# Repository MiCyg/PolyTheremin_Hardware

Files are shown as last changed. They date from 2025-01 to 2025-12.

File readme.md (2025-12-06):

# Polytheremin Hardware


[← Back to main repository](https://github.com/MiCyg/PolyTheremin.git)

---

# PolyTheremin Test Platform  

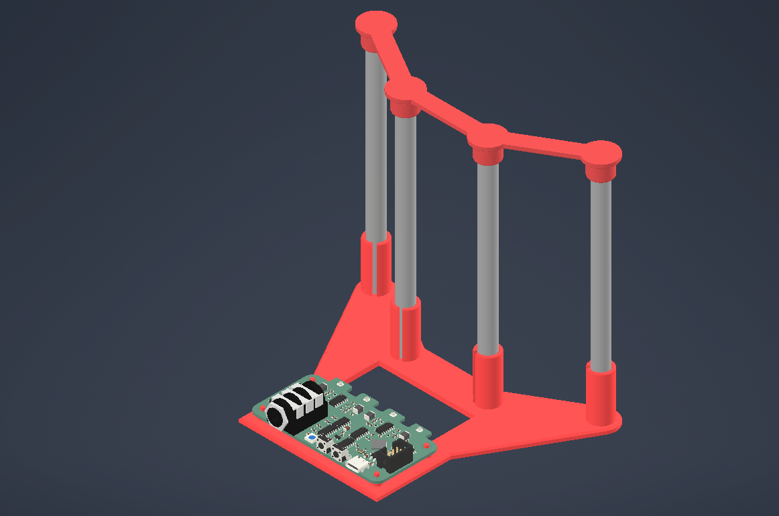
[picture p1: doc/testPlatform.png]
PolyTheremin Test Platform


# Description  

This test platform features a main board with four capacitive proximity sensors based on [OpenTheremin](https://github.com/GaudiLabs/OpenThereminV4) electronics.  

The key improvement in this version is the replacement of the fixed-frequency oscillator with a microcontroller-driven heterodyne frequency generator. This modification simplifies the circuit design and calibration process.  

The platform enables the analysis of antenna correlation errors, visualized on an XY plot.  
Its ultimate goal is to provide a functional example of a PolyTheremin with four independent oscillators, significantly reducing finger cross-correlation.

# PCB Characteristics  
- **Microcontroller**: RP2040  
- **LED**: One addressable LED for status indication  
- **Oscillator Modules**: Four theremin modules, independently connected to the microcontroller  
- **Audio Output**: Four 12-bit DACs (MCP4922) with a mixer and a 6.3mm jack socket  

# Block Schematic  
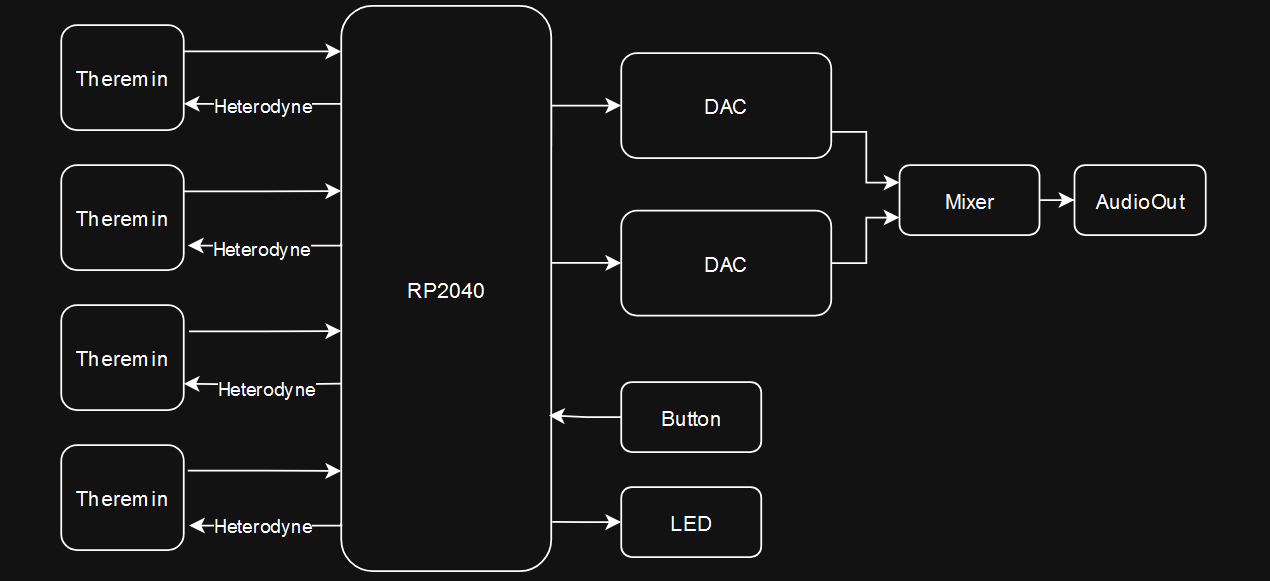
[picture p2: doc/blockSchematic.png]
Block Schematic


# 3D View  
3D View

# Contribution  

Contributions are welcome!  
If you have suggestions, encounter any issues, or want to discuss the project, feel free to contact me or open a pull request.

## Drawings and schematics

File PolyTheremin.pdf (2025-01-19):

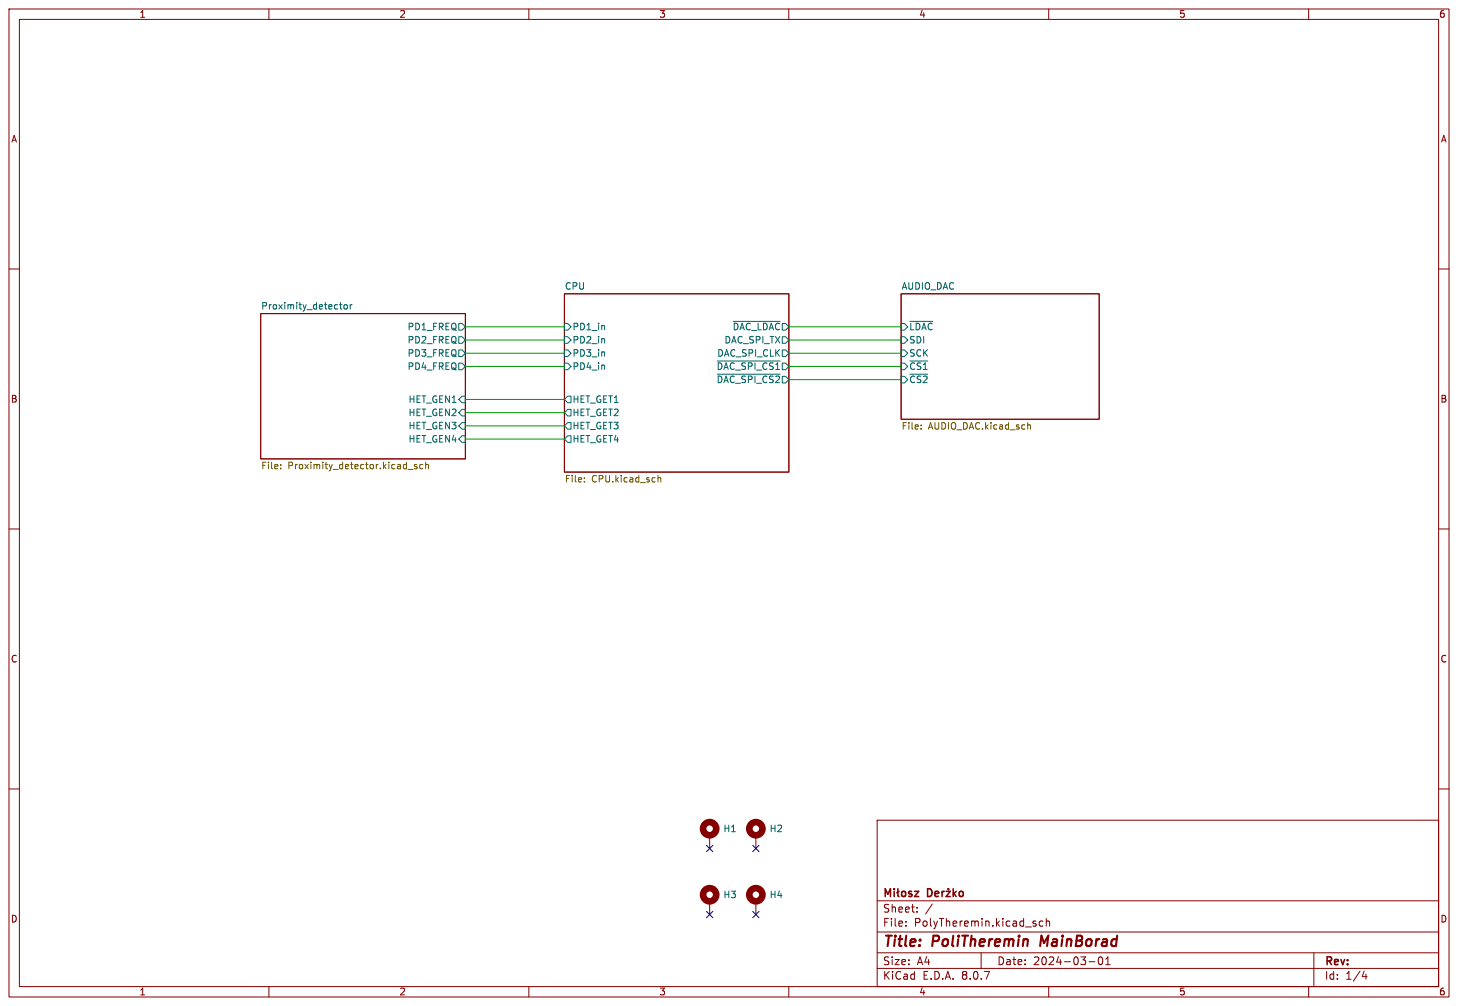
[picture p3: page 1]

File: PolyTheremin.kicad_sch Sheet: / þÿMiBosz þÿDer|ko

Id: 1/4 Title: PoliTheremin MainBorad

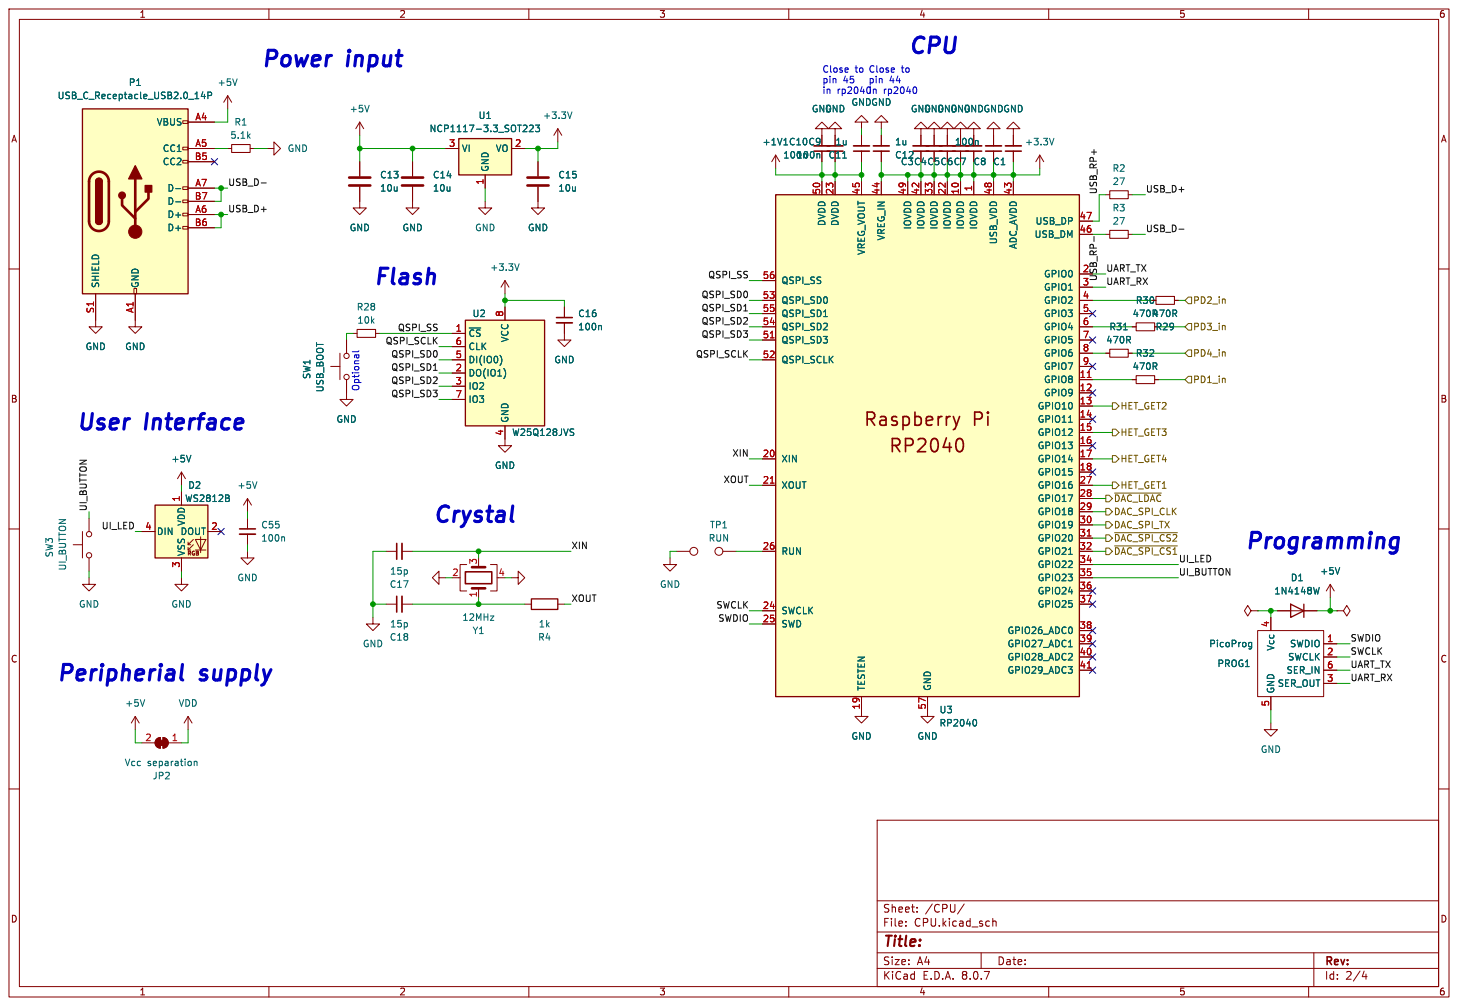
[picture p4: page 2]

1 IOVDD 10 GPIO8 11 GPIO9 12 GPIO10 13 GPIO11 14 GPIO12 15 GPIO13 16 GPIO14 17 GPIO15 18 TESTEN 19 GPIO0 2 XIN 20 XOUT 21 IOVDD 22 DVDD 23 SWCLK 24 SWD 25 RUN 26 GPIO16 27 GPIO17 28 GPIO18 29 GPIO1 3 GPIO19 30 GPIO20 31 GPIO21 32 IOVDD 33 GPIO22 34 GPIO23 35 GPIO24 36 GPIO25 37 GPIO26_ADC0 38 GPIO27_ADC1 39 GPIO2 4 GPIO28_ADC2 40 GPIO29_ADC3 41 IOVDD 42 ADC_AVDD 43 VREG_IN 44 VREG_VOUT 45 USB_DM 46 USB_DP 47 USB_VDD 48 IOVDD 49 GPIO3 5 DVDD 50 QSPI_SD3 51 QSPI_SCLK 52 QSPI_SD0 53 QSPI_SD2 54 QSPI_SD1 55 QSPI_SS 56 GND 57 GPIO4 6 GPIO5 7 GPIO6 8 GPIO7 9 U3 RP2040

1 IOVDD 10 GPIO8 11 GPIO9 12 GPIO10 13 GPIO11 14 GPIO12 15 GPIO13 16 GPIO14 17 GPIO15 18 TESTEN 19 GPIO0 2 XIN 20 XOUT 21 IOVDD 22 DVDD 23 SWCLK 24 SWD 25 RUN 26 GPIO16 27 GPIO17 28 GPIO18 29 GPIO1 3 GPIO19 30 GPIO20 31 GPIO21 32 IOVDD 33 GPIO22 34 GPIO23 35 GPIO24 36 GPIO25 37 GPIO26_ADC0 38 GPIO27_ADC1 39 GPIO2 4 GPIO28_ADC2 40 GPIO29_ADC3 41 IOVDD 42 ADC_AVDD 43 VREG_IN 44 VREG_VOUT 45 USB_DM 46 USB_DP 47 USB_VDD 48 IOVDD 49 GPIO3 5 DVDD 50 QSPI_SD3 51 QSPI_SCLK 52 QSPI_SD0 53 QSPI_SD2 54 QSPI_SD1 55 QSPI_SS 56 GND 57 GPIO4 6 GPIO5 7 GPIO6 8 GPIO7 9 GND

Id: 2/4 Title: File: CPU.kicad_sch Sheet: /CPU/ GND

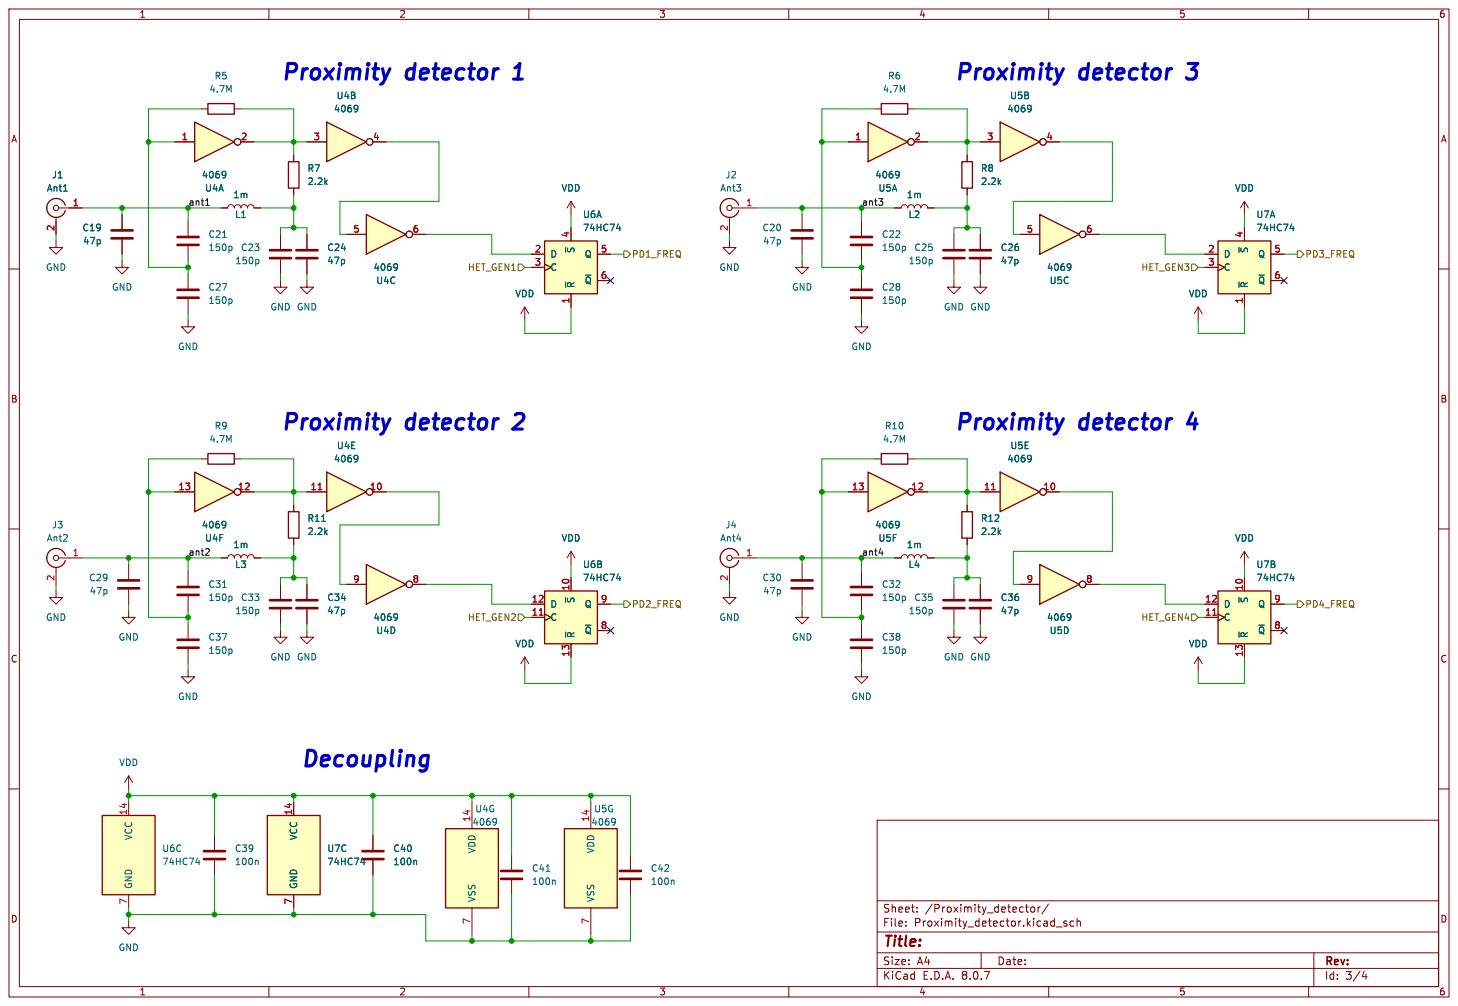
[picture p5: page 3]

Id: 3/4 Title: File: Proximity_detector.kicad_sch Sheet: /Proximity_detector/

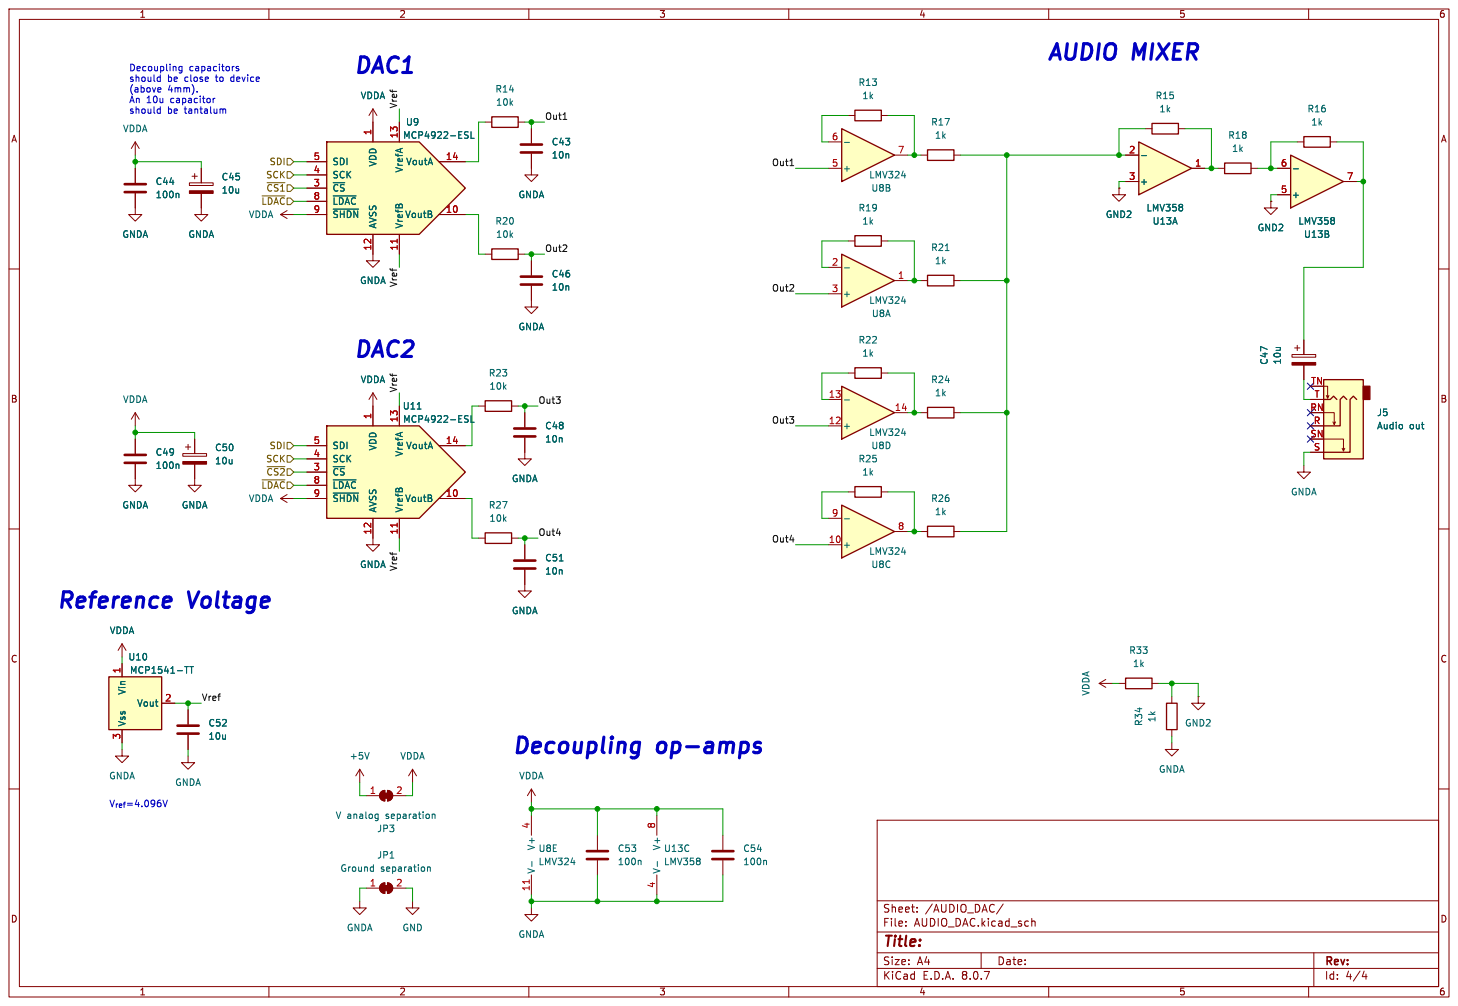
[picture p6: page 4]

should be close to device
100n VDDA

1 VoutB 10 VrefB 11 AVSS 12 VrefA 13 VoutA 14 ~{CS} 3 SCK 4 SDI 5 ~{LDAC} 8 ~{SHDN} 9 U9 MCP4922-ESL GNDA C44

1 VoutB 10 VrefB 11 AVSS 12 VrefA 13 VoutA 14 ~{CS} 3 SCK 4 SDI 5 ~{LDAC} 8 ~{SHDN} 9 GNDA C43

1 VoutB 10 VrefB 11 AVSS 12 VrefA 13 VoutA 14 ~{CS} 3 SCK 4 SDI 5 ~{LDAC} 8 ~{SHDN} 9 GNDA GNDA GNDA GNDAC52

1 VoutB 10 VrefB 11 AVSS 12 VrefA 13 VoutA 14 ~{CS} 3 SCK 4 SDI 5 ~{LDAC} 8 ~{SHDN} 9 U11 MCP4922-ESL R

1 Vout 2 Vss 3 U10 MCP1541-TT VDDA C50

Id: 4/4 Title: File: AUDIO_DAC.kicad_sch Sheet: /AUDIO_DAC/

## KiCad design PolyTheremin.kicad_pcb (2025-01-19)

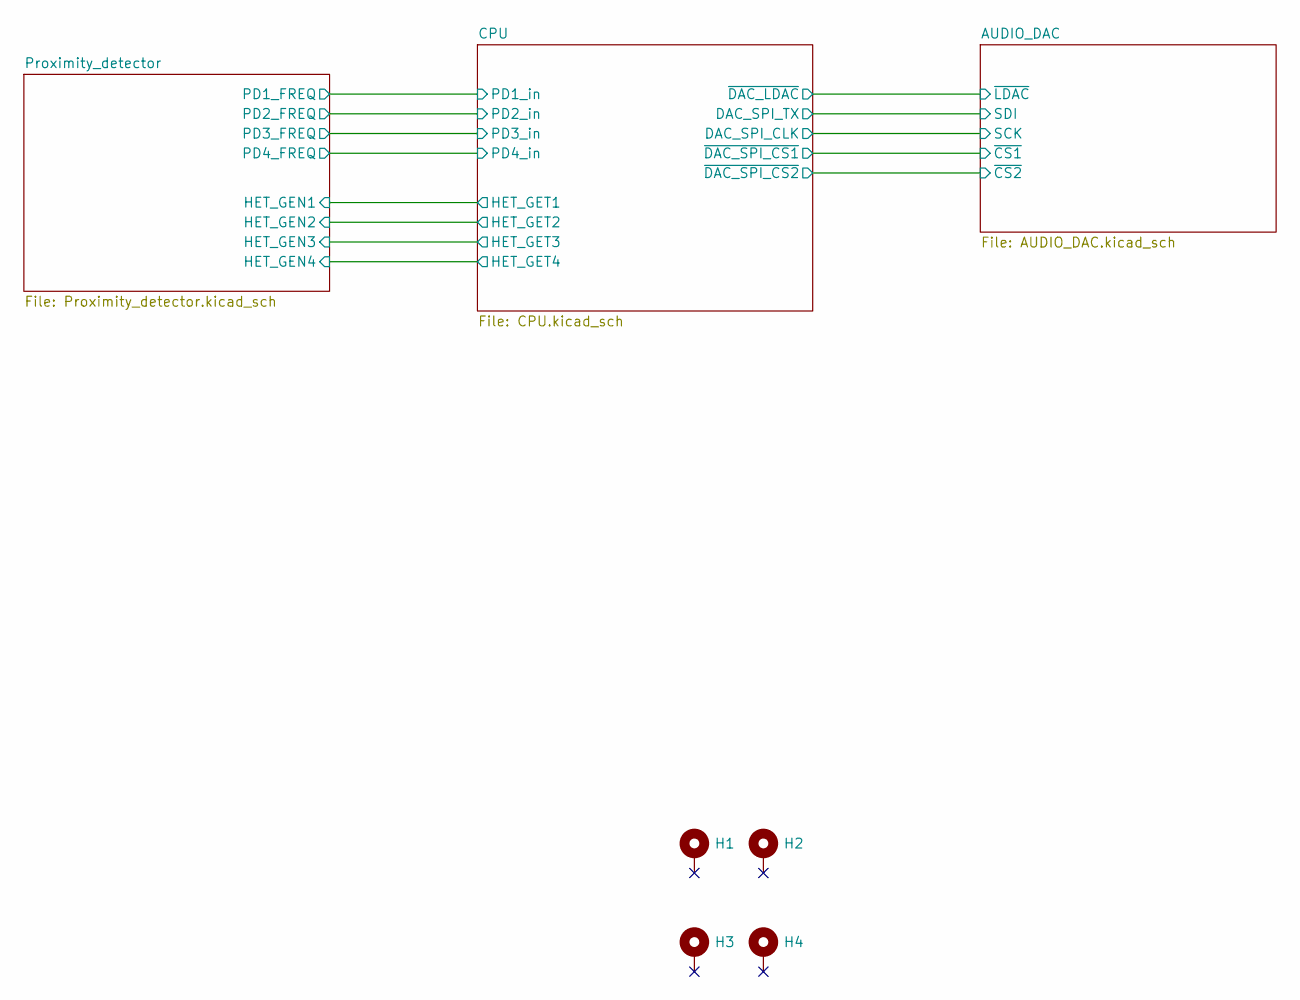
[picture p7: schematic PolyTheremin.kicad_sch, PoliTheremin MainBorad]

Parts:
H1, H2, H3, H4: MountingHole_Pad; MountingHole_3.2mm_M3_Pad_Via

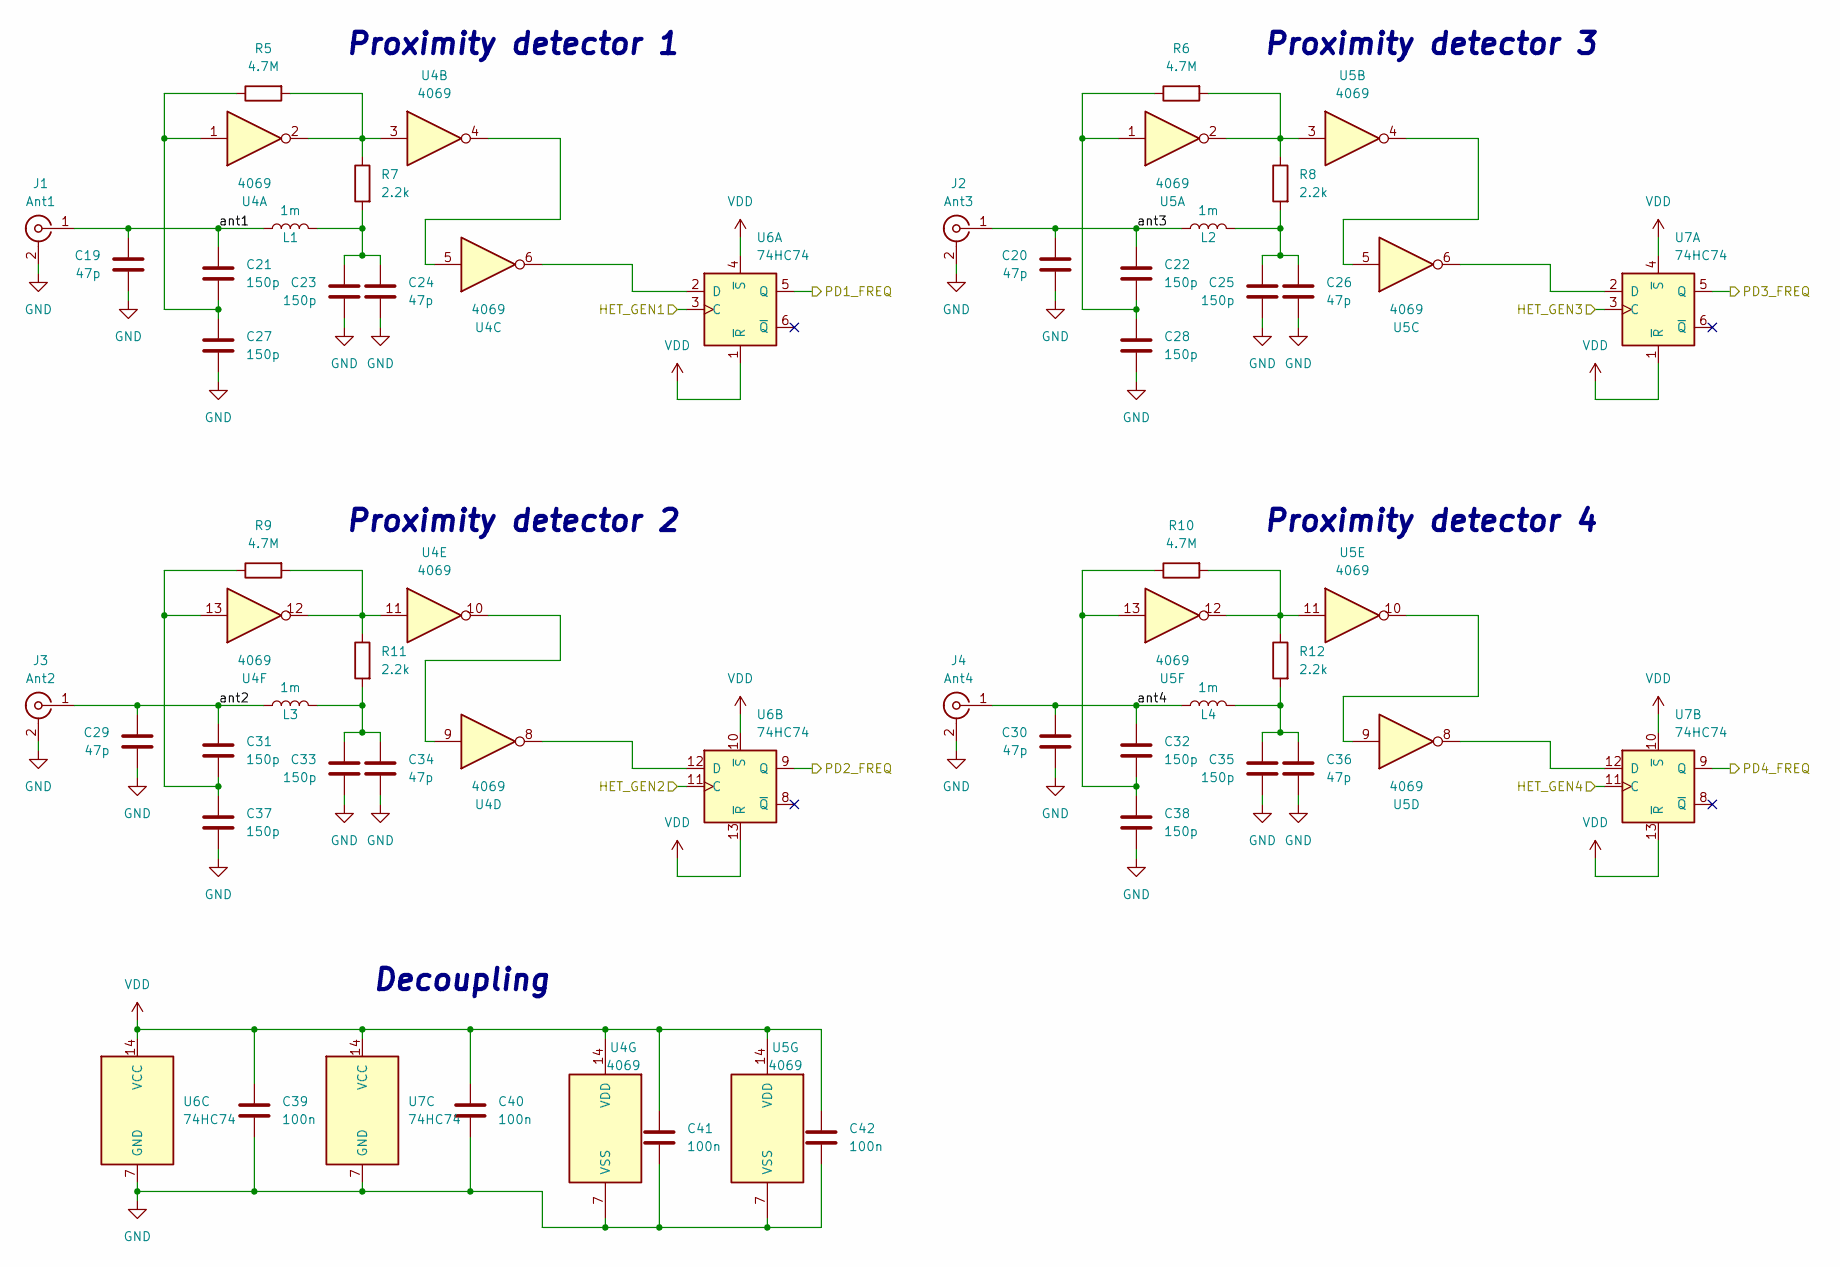
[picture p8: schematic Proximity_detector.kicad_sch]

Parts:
C19, C20, C24, C26, C29, C30, C34, C36: 47p; C_0603_1608Metric_Pad1.08x0.95mm_HandSolder
C21, C22, C23, C25, C27, C28, C31, C32, C33, C35, C37, C38: 150p; C_0603_1608Metric_Pad1.08x0.95mm_HandSolder
C39, C40, C41, C42: 100n; C_0603_1608Metric_Pad1.08x0.95mm_HandSolder
J1: Ant1; U.FL_Molex_MCRF_73412-0110_Vertical
J2: Ant3; U.FL_Molex_MCRF_73412-0110_Vertical
J3: Ant2; U.FL_Molex_MCRF_73412-0110_Vertical
J4: Ant4; U.FL_Molex_MCRF_73412-0110_Vertical
L1, L2, L3, L4: 1m; L_1812_4532Metric_Pad1.30x3.40mm_HandSolder
R5, R6, R9, R10: 4.7M; R_0603_1608Metric_Pad0.98x0.95mm_HandSolder
R7, R8, R11, R12: 2.2k; R_0603_1608Metric_Pad0.98x0.95mm_HandSolder
U4, U5: 4069; SOIC-14_3.9x8.7mm_P1.27mm
U6, U7: 74HC74; SOIC-14_3.9x8.7mm_P1.27mm

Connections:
/CPU/HET_GET1: U6.3 (C); also elsewhere on the board
/CPU/HET_GET2: U6.11 (C); also elsewhere on the board
/CPU/HET_GET3: U7.3 (C); also elsewhere on the board
/CPU/HET_GET4: U7.11 (C); also elsewhere on the board
/CPU/PD1_in: U6.5 (Q); also elsewhere on the board
/CPU/PD2_in: U6.9 (Q); also elsewhere on the board
/CPU/PD3_in: U7.5 (Q); also elsewhere on the board
/CPU/PD4_in: U7.9 (Q); also elsewhere on the board
/Proximity_detector/ant1: C19.1, C21.1, J1.1 (In), L1.2
/Proximity_detector/ant2: C29.1, C31.1, J3.1 (In), L3.2
/Proximity_detector/ant3: C20.1, C22.1, J2.1 (In), L2.2
/Proximity_detector/ant4: C30.1, C32.1, J4.1 (In), L4.2
GND: C19.2, C20.2, C23.2, C24.2, C25.2, C26.2, C27.2, C28.2, C29.2, C30.2, C33.2, C34.2, C35.2, C36.2, C37.2, C38.2, C39.2, C40.2, C41.2, C42.2, J1.2 (Ext), J2.2 (Ext), J3.2 (Ext), J4.2 (Ext), U4.7 (VSS), U5.7 (VSS), U6.7 (GND), U7.7 (GND); also elsewhere on the board
unnamed: C21.2, C27.1, R5.1, U4.1
unnamed: C22.2, C28.1, R6.1, U5.1
unnamed: C23.1, C24.1, L1.1, R7.2
unnamed: C25.1, C26.1, L2.1, R8.2
unnamed: C31.2, C37.1, R9.1, U4.13
unnamed: C32.2, C38.1, R10.1, U5.13
unnamed: C33.1, C34.1, L3.1, R11.2
unnamed: C35.1, C36.1, L4.1, R12.2
unnamed: R5.2, R7.1, U4.2, U4.3
unnamed: R6.2, R8.1, U5.2, U5.3
unnamed: R10.2, R12.1, U5.11, U5.12
unnamed: R9.2, R11.1, U4.11, U4.12
unnamed: U4.4, U4.5
unnamed: U4.9, U4.10
unnamed: U5.4, U5.5
unnamed: U5.9, U5.10
unnamed: U4.6, U6.2 (D)
unnamed: U4.8, U6.12 (D)
unnamed: U5.6, U7.2 (D)
unnamed: U5.8, U7.12 (D)
VDD: C39.1, C40.1, C41.1, C42.1, U4.14 (VDD), U5.14 (VDD), U6.1 (~R), U6.4 (~S), U6.10 (~S), U6.13 (~R), U6.14 (VCC), U7.1 (~R), U7.4 (~S), U7.10 (~S), U7.13 (~R), U7.14 (VCC); also elsewhere on the board

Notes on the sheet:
Decoupling
Proximity detector 1
Proximity detector 3
Proximity detector 4
Proximity detector 2

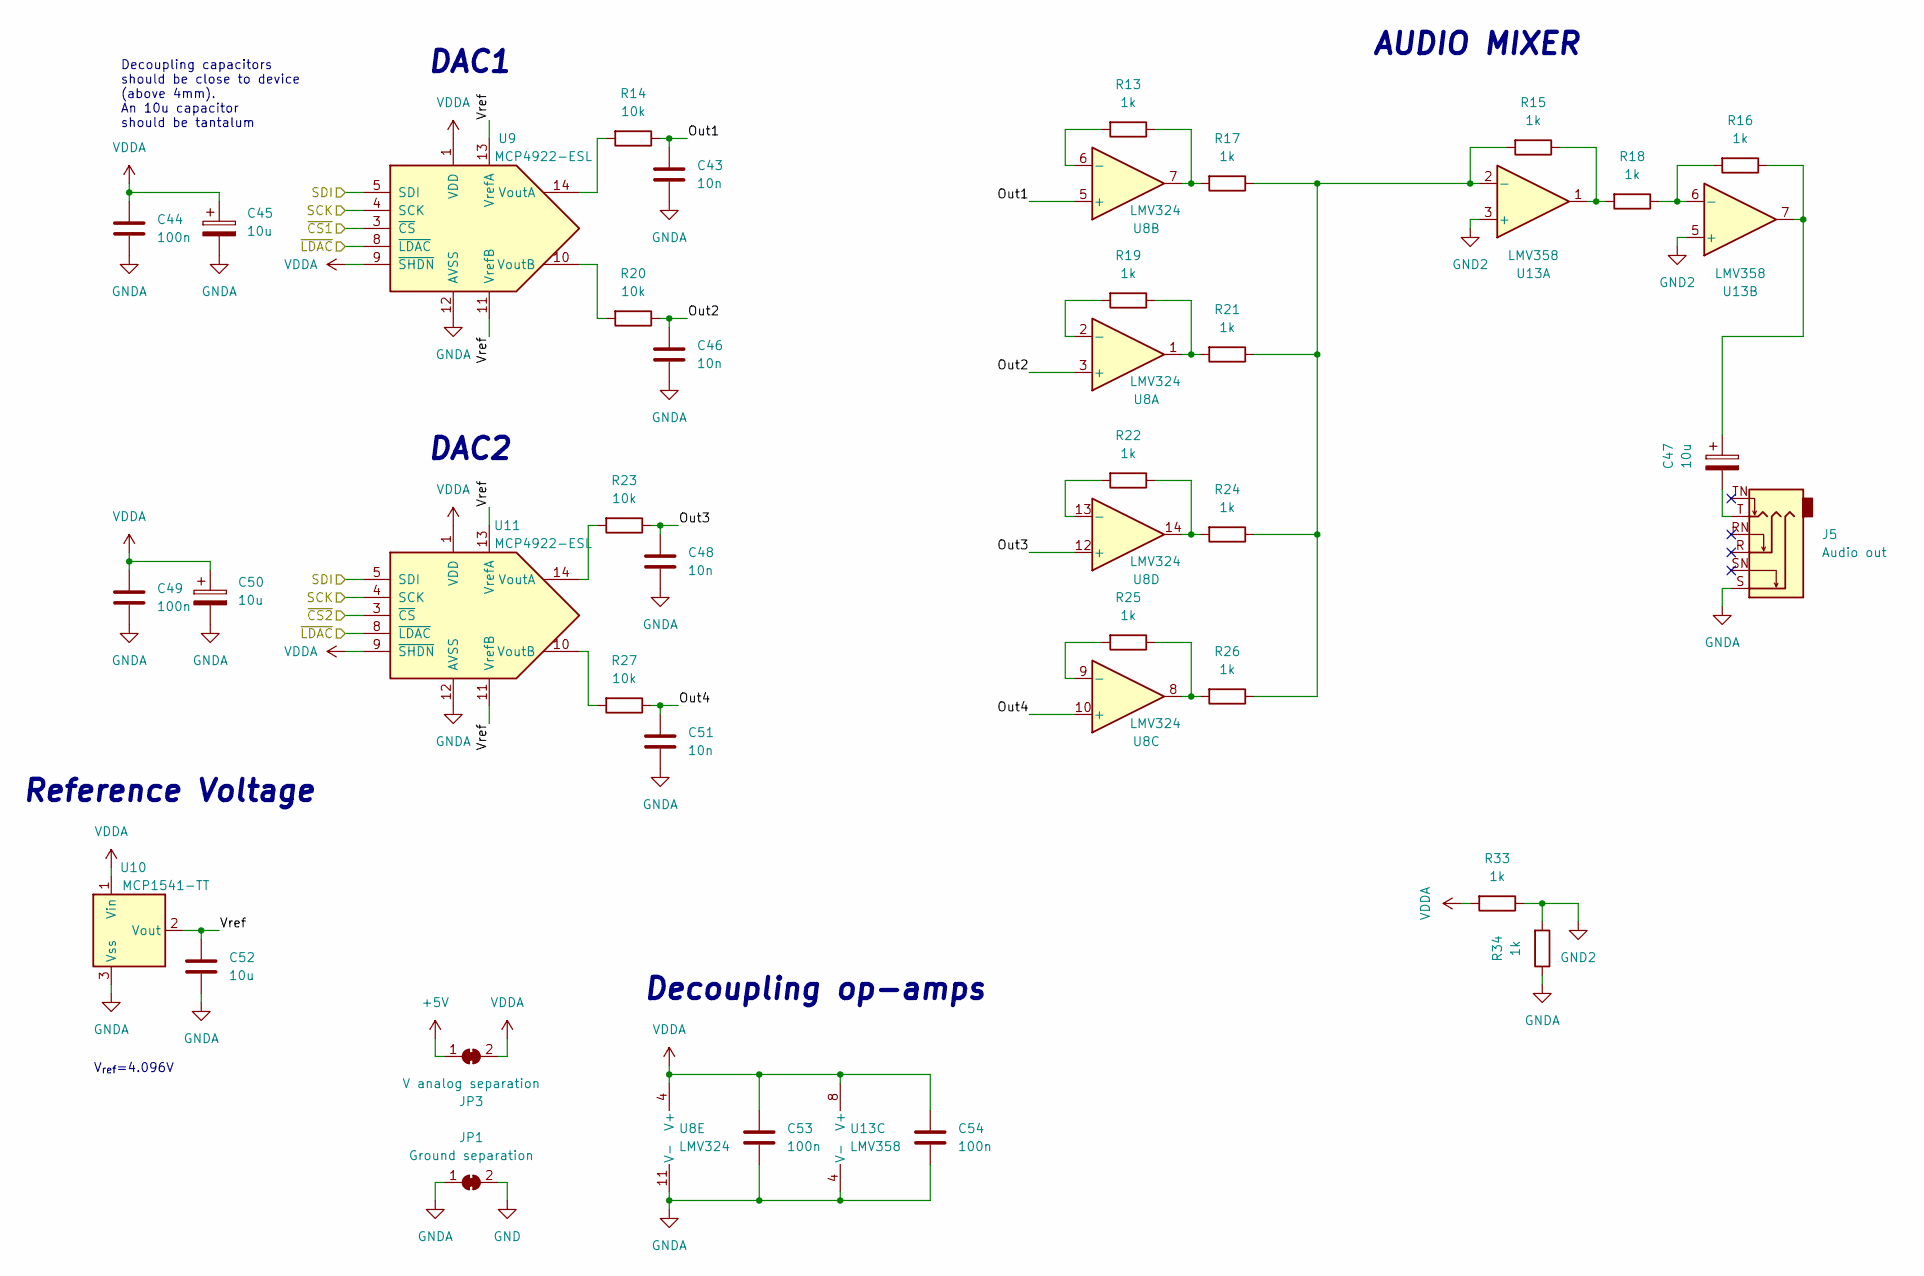
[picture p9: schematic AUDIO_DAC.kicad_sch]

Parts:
C43, C46, C48, C51: 10n; C_0603_1608Metric_Pad1.08x0.95mm_HandSolder
C44, C49, C53, C54: 100n; C_0603_1608Metric_Pad1.08x0.95mm_HandSolder
C45, C50: 10u; C_1206_3216Metric_Pad1.33x1.80mm_HandSolder
C47: 10u; C_0805_2012Metric_Pad1.18x1.45mm_HandSolder
C52: 10u; C_0603_1608Metric_Pad1.08x0.95mm_HandSolder
J5: Audio out; Jack_6.35mm_Neutrik_NMJ6HFD2_Horizontal
JP1: Ground separation; SolderJumper-2_P1.3mm_Open_RoundedPad1.0x1.5mm
JP3: V analog separation; SolderJumper-2_P1.3mm_Open_RoundedPad1.0x1.5mm
R13, R15, R16, R17, R18, R19, R21, R22, R24, R25, R26, R33, R34: 1k; R_0603_1608Metric_Pad0.98x0.95mm_HandSolder
R14, R20, R23, R27: 10k; R_0603_1608Metric_Pad0.98x0.95mm_HandSolder
U8: LMV324; SOIC-14_3.9x8.7mm_P1.27mm
U9, U11: MCP4922-ESL; SOIC-14_3.9x8.7mm_P1.27mm
U10: MCP1541-TT; SOT-23
U13: LMV358; SO-8_3.9x4.9mm_P1.27mm

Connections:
+5V: JP3.1 (A); also elsewhere on the board
/AUDIO_DAC/Out1: C43.1, R14.1, U8.5 (+)
/AUDIO_DAC/Out2: C46.1, R20.1, U8.3 (+)
/AUDIO_DAC/Out3: C48.1, R23.1, U8.12 (+)
/AUDIO_DAC/Out4: C51.1, R27.1, U8.10 (+)
/AUDIO_DAC/SCK: U9.4 (SCK), U11.4 (SCK); also elsewhere on the board
/AUDIO_DAC/SDI: U9.5 (SDI), U11.5 (SDI); also elsewhere on the board
/AUDIO_DAC/Vref: C52.1, U9.11 (VrefB), U9.13 (VrefA), U10.2 (Vout), U11.11 (VrefB), U11.13 (VrefA)
/AUDIO_DAC/~CS1: U9.3 (~CS); also elsewhere on the board
/AUDIO_DAC/~CS2: U11.3 (~CS); also elsewhere on the board
/AUDIO_DAC/~LDAC: U9.8 (~LDAC), U11.8 (~LDAC); also elsewhere on the board
GND: JP1.2 (B); also elsewhere on the board
unnamed: C47.1, R16.1, U13.7
unnamed: C47.2, J5.T
unnamed: R13.1, R17.2, U8.7
unnamed: R15.1, R18.2, U13.1
unnamed: R19.1, R21.2, U8.1
unnamed: R22.1, R24.2, U8.14
unnamed: R25.1, R26.2, U8.8
unnamed: R19.2, U8.2 (-)
unnamed: R13.2, U8.6 (-)
unnamed: R25.2, U8.9 (-)
unnamed: R22.2, U8.13 (-)
unnamed: R14.2, U9.14 (VoutA)
unnamed: R20.2, U9.10 (VoutB)
unnamed: R23.2, U11.14 (VoutA)
unnamed: R27.2, U11.10 (VoutB)
unnamed: R15.2, R17.1, R21.1, R24.1, R26.1, U13.2 (-)
unnamed: R16.2, R18.1, U13.6 (-)
VDDA: C44.1, C45.1, C49.1, C50.1, C53.1, C54.1, JP3.2 (B), R33.2, U8.4 (V+), U9.1 (VDD), U9.9 (~SHDN), U10.1 (Vin), U11.1 (VDD), U11.9 (~SHDN), U13.8 (V+)

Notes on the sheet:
AUDIO MIXER
Reference Voltage
DAC2
Decoupling op-amps
Decoupling capacitors should be close to device (above 4mm). An 10u capacitor should be tantalum
V_{ref}=4.096V
DAC1

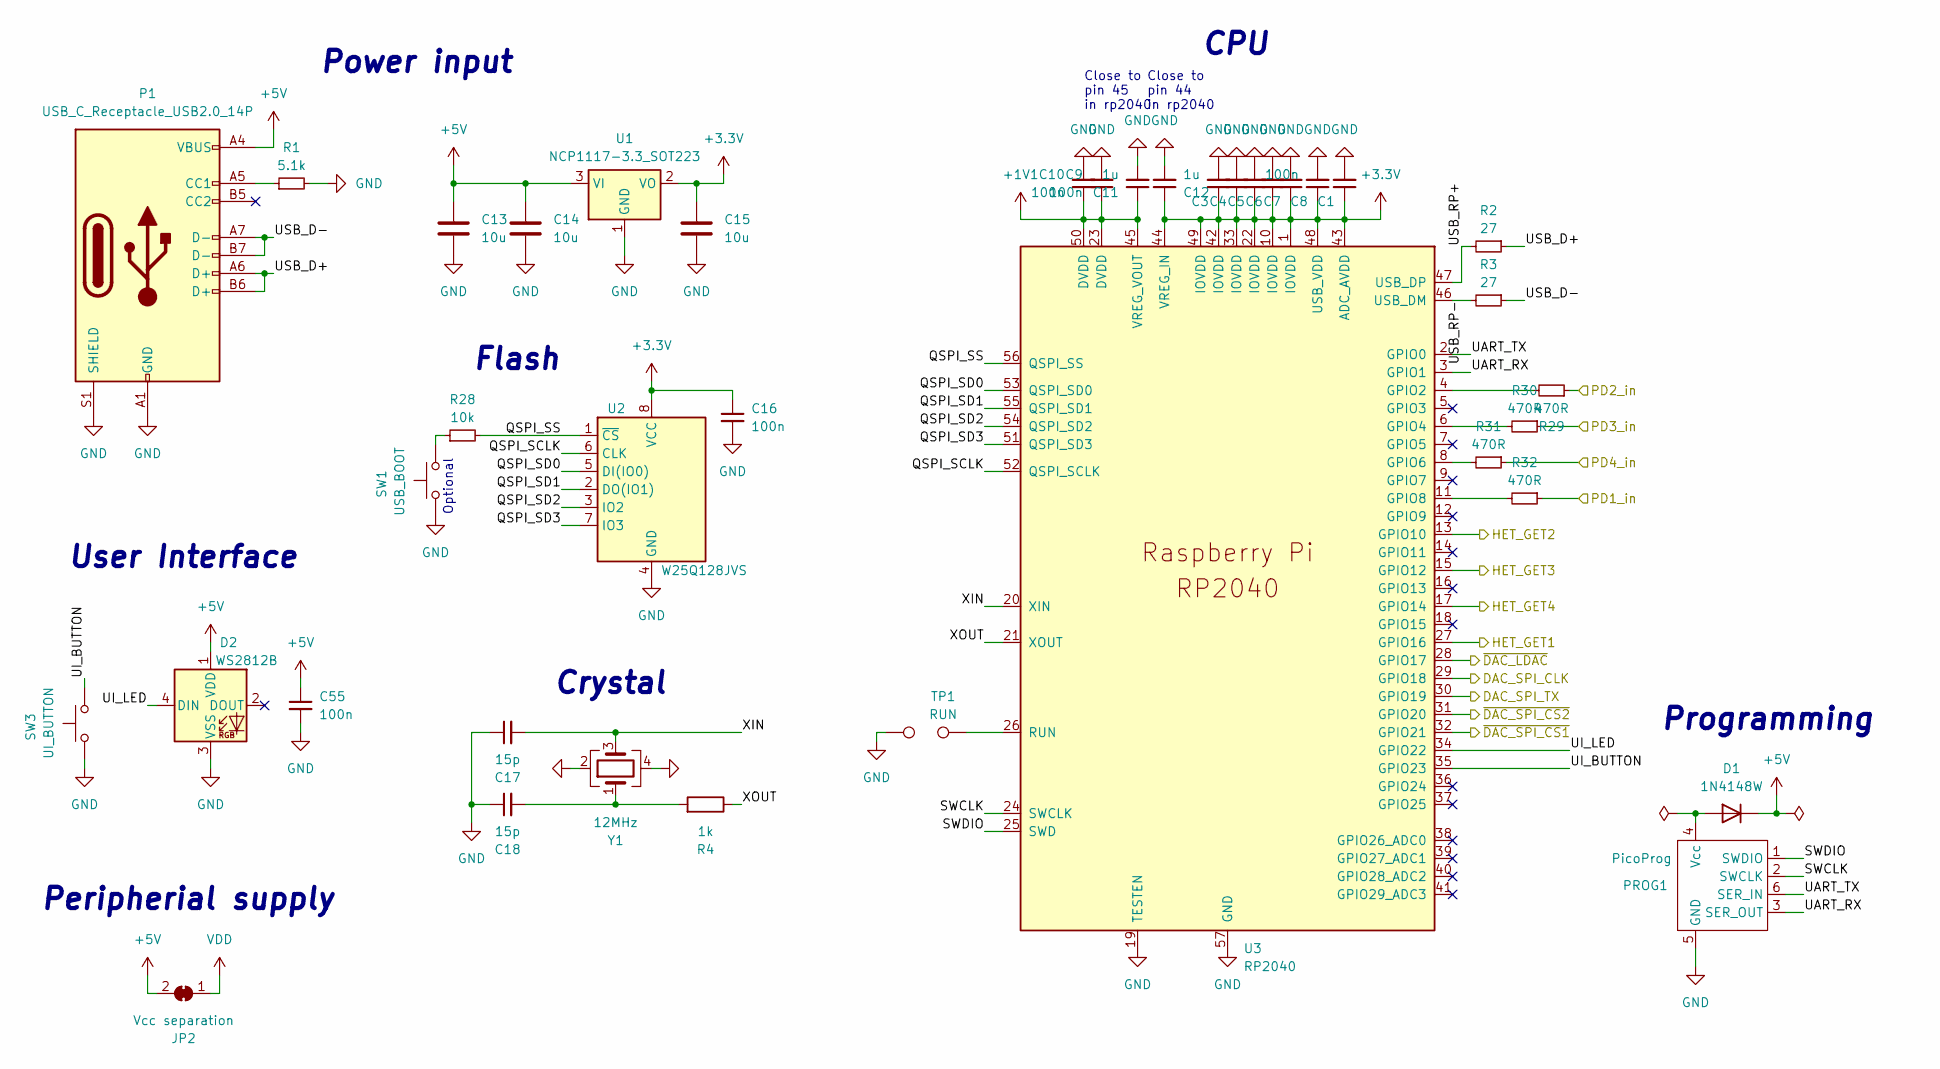
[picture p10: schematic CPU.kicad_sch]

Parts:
C1, C3, C4, C5, C6, C7, C8, C9, C10, C16, C55: 100n; C_0603_1608Metric_Pad1.08x0.95mm_HandSolder
C11, C12: 1u; C_0603_1608Metric_Pad1.08x0.95mm_HandSolder
C13, C14, C15: 10u; C_0805_2012Metric_Pad1.18x1.45mm_HandSolder
C17, C18: 15p; C_0603_1608Metric_Pad1.08x0.95mm_HandSolder
D1: 1N4148W; D_SOD-123
D2: WS2812B; LED_WS2812B_PLCC4_5.0x5.0mm_P3.2mm
JP2: Vcc separation; SolderJumper-2_P1.3mm_Open_RoundedPad1.0x1.5mm
P1: USB_C_Receptacle_USB2.0_14P; USB_C_Receptacle_G-Switch_GT-USB-7010ASV
PROG1: PicoProg; IDC-Header_2x03_P2.54mm_Vertical
R1: 5.1k; R_0603_1608Metric_Pad0.98x0.95mm_HandSolder
R2, R3: 27; R_0603_1608Metric_Pad0.98x0.95mm_HandSolder
R4: 1k; R_0603_1608Metric_Pad0.98x0.95mm_HandSolder
R28: 10k; R_0603_1608Metric_Pad0.98x0.95mm_HandSolder
R29, R30, R31, R32: 470R; R_0603_1608Metric_Pad0.98x0.95mm_HandSolder
SW1: USB_BOOT; SW_Tactile_SPST_Angled_PTS645Vx31-2LFS
SW3: UI_BUTTON; SW_Tactile_SPST_Angled_PTS645Vx31-2LFS
TP1: RUN
TP2: TestPoint
U1: NCP1117-3.3_SOT223; SOT-223-3_TabPin2
U2: W25Q128JVS; SOIC-8_5.23x5.23mm_P1.27mm
U3: RP2040; QFN-56-1EP_7x7mm_P0.4mm_EP3.2x3.2mm
Y1: 12MHz; Crystal_SMD_2520-4Pin_2.5x2.0mm

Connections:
+1V1: C9.1, C10.1, C11.1, U3.23 (DVDD), U3.45 (VREG_VOUT), U3.50 (DVDD)
+3.3V: C1.1, C3.1, C4.1, C5.1, C6.1, C7.1, C8.1, C12.1, C15.1, C16.1, U1.2 (VO), U2.8 (VCC), U3.1 (IOVDD), U3.10 (IOVDD), U3.22 (IOVDD), U3.33 (IOVDD), U3.42 (IOVDD), U3.43 (ADC_AVDD), U3.44 (VREG_IN), U3.48 (USB_VDD), U3.49 (IOVDD)
+5V: C13.1, C14.1, C55.1, D1.1 (K), D2.1 (VDD), JP2.2 (B), P1.A4 (VBUS), P1.A9 (VBUS), P1.B4 (VBUS), P1.B9 (VBUS), U1.3 (VI); also elsewhere on the board
/AUDIO_DAC/SCK: U3.29 (GPIO18); also elsewhere on the board
/AUDIO_DAC/SDI: U3.30 (GPIO19); also elsewhere on the board
/AUDIO_DAC/~CS1: U3.32 (GPIO21); also elsewhere on the board
/AUDIO_DAC/~CS2: U3.31 (GPIO20); also elsewhere on the board
/AUDIO_DAC/~LDAC: U3.28 (GPIO17); also elsewhere on the board
/CPU/HET_GET1: U3.27 (GPIO16); also elsewhere on the board
/CPU/HET_GET2: U3.13 (GPIO10); also elsewhere on the board
/CPU/HET_GET3: U3.15 (GPIO12); also elsewhere on the board
/CPU/HET_GET4: U3.17 (GPIO14); also elsewhere on the board
/CPU/PD1_in: R32.1; also elsewhere on the board
/CPU/PD2_in: R29.1; also elsewhere on the board
/CPU/PD3_in: R30.1; also elsewhere on the board
/CPU/PD4_in: R31.1; also elsewhere on the board
/CPU/QSPI_SCLK: U2.6 (CLK), U3.52 (QSPI_SCLK)
/CPU/QSPI_SD0: U2.5 (DI(IO0)), U3.53 (QSPI_SD0)
/CPU/QSPI_SD1: U2.2 (DO(IO1)), U3.55 (QSPI_SD1)
/CPU/QSPI_SD2: U2.3 (IO2), U3.54 (QSPI_SD2)
/CPU/QSPI_SD3: U2.7 (IO3), U3.51 (QSPI_SD3)
/CPU/QSPI_SS: R28.2, U2.1 (~CS), U3.56 (QSPI_SS)
/CPU/SWCLK: PROG1.2 (SWCLK), U3.24 (SWCLK)
/CPU/SWDIO: PROG1.1 (SWDIO), U3.25 (SWD)
/CPU/UART_RX: PROG1.3 (SER_OUT), U3.3 (GPIO1)
/CPU/UART_TX: PROG1.6 (SER_IN), U3.2 (GPIO0)
/CPU/UI_BUTTON: SW3.1, U3.35 (GPIO23)
/CPU/UI_LED: D2.4 (DIN), U3.34 (GPIO22)
/CPU/USB_D+: P1.A6 (D+), P1.B6 (D+), R2.1
/CPU/USB_D-: P1.A7 (D-), P1.B7 (D-), R3.1
/CPU/USB_RP+: R2.2, U3.47 (USB_DP)
/CPU/USB_RP-: R3.2, U3.46 (USB_DM)
/CPU/XIN: C17.2, U3.20 (XIN), Y1.3
/CPU/XOUT: R4.1, U3.21 (XOUT)
GND: C1.2, C3.2, C4.2, C5.2, C6.2, C7.2, C8.2, C9.2, C10.2, C11.2, C12.2, C13.2, C14.2, C15.2, C16.2, C17.1, C18.1, C55.2, D2.3 (VSS), P1.A1 (GND), P1.A12 (GND), P1.B1 (GND), P1.B12 (GND), P1.S1 (SHIELD), PROG1.5 (GND), R1.2, SW1.2, SW3.2, TP2.1, U1.1 (GND), U2.4 (GND), U3.19 (TESTEN), U3.57 (GND), Y1.2, Y1.4; also elsewhere on the board
unnamed: C18.2, R4.2, Y1.1
unnamed: D1.2 (A), PROG1.4 (Vcc)
unnamed: P1.A5 (CC1), R1.1
unnamed: R28.1, SW1.1
unnamed: TP1.1, U3.26 (RUN)
unnamed: R29.2, U3.4 (GPIO2)
unnamed: R30.2, U3.6 (GPIO4)
unnamed: R31.2, U3.8 (GPIO6)
unnamed: R32.2, U3.11 (GPIO8)
VDD: JP2.1 (A); also elsewhere on the board

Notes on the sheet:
Flash
Close to pin 44 in rp2040
Crystal
Close to pin 45 in rp2040
Peripherial supply
Optional
CPU
User Interface
Programming
Power input

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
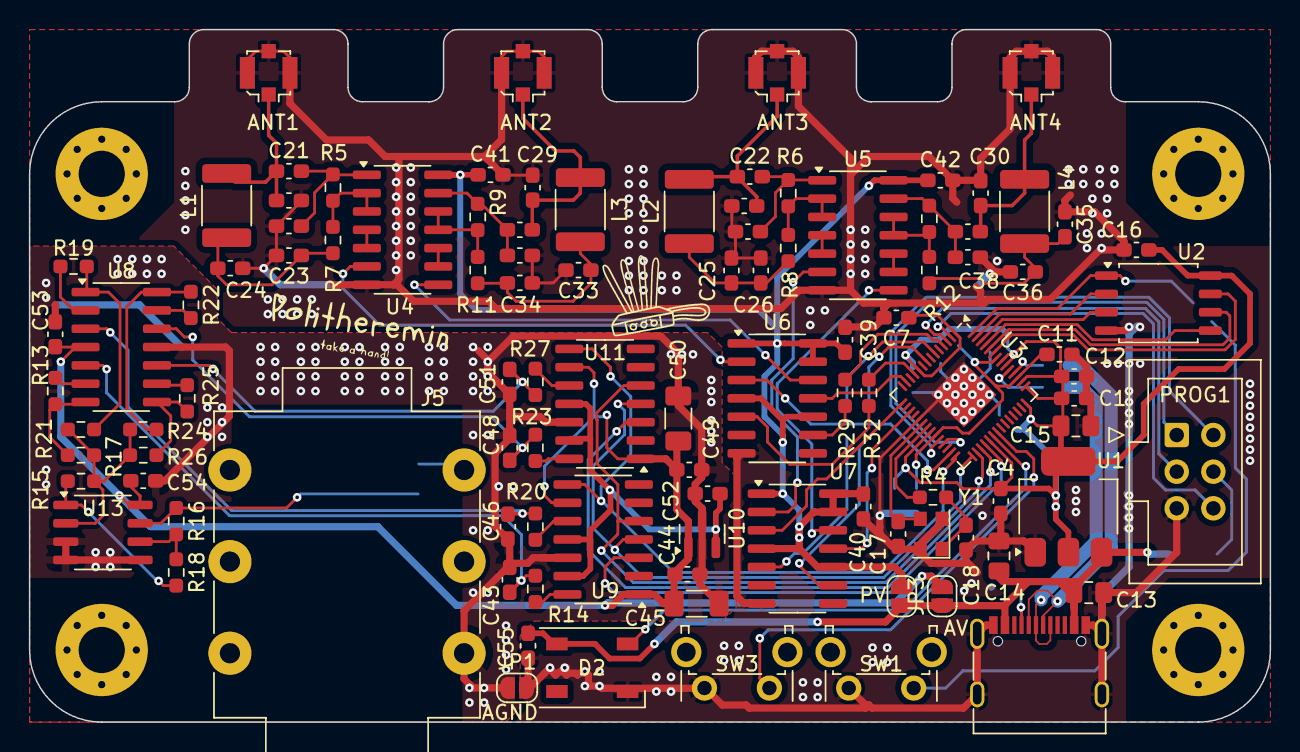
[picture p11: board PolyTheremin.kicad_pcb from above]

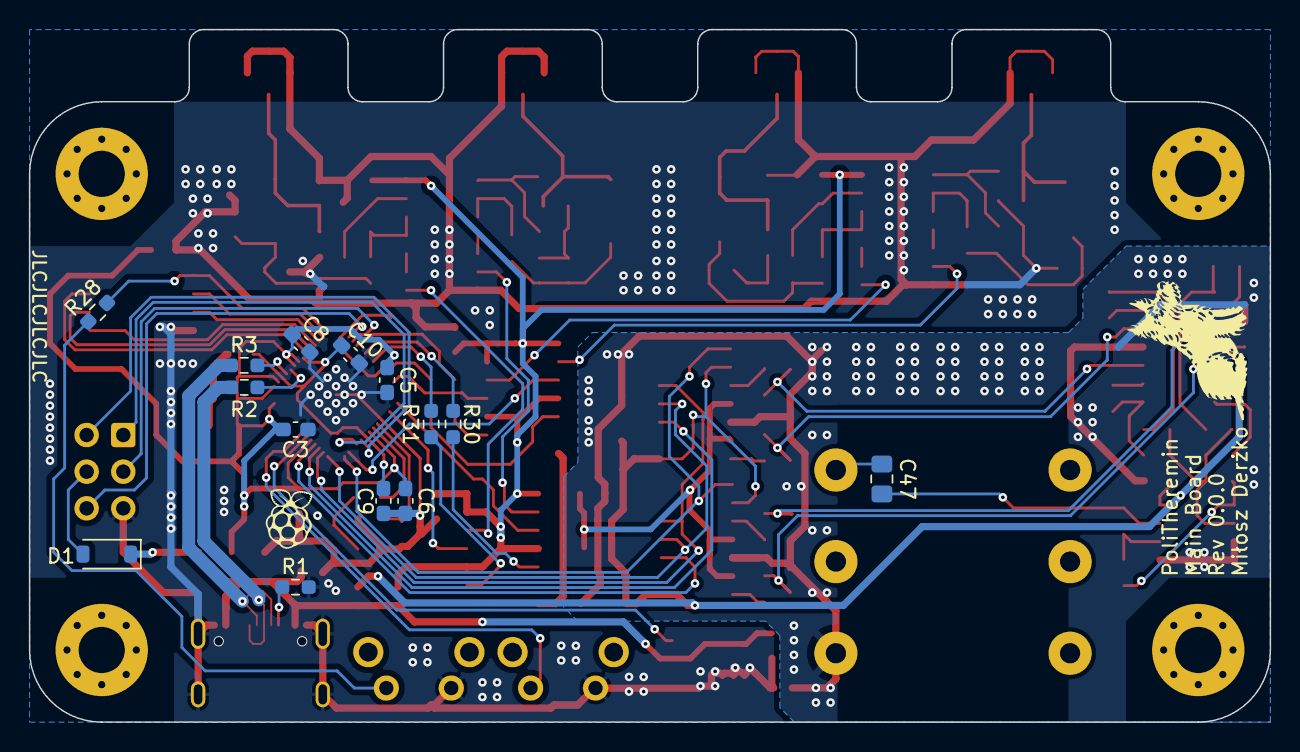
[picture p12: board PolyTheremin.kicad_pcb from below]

Board: 2 copper layers, 86.0 x 48.0 mm, 121 parts (14 on the bottom side), 92 nets.

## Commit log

2024-12-25 chore: git init
    [AUDIO_DAC.kicad_sch, CPU.kicad_sch, PolyTheremin.kicad_pcb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]
2025-01-18 feat: Add proper 3d footprint path
    [PolyTheremin.kicad_pcb]
2025-01-18 feat: Update element path
    [PolyTheremin.kicad_pcb]
2025-01-19 feat: Update path to eeprom
    [PolyTheremin.kicad_pcb]
2025-01-19 feat: Update pdf schematic
2025-10-03 fix: Remove second DAC
    [AUDIO_DAC.kicad_sch, CPU.kicad_sch, PolyTheremin.kicad_sch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]
